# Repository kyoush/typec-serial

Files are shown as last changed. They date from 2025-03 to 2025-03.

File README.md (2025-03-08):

# typec-serial

USB Type-C to serial UART変換基板のKiCadプロジェクト

## 仕様

- ホストPC接続インタフェース: USB Type-C レセプタクル
- UARTデバイス接続インタフェース: 2.54mmピッチ4pinピンヘッダ \
  (実際の通信は、GND, RX, TXだけ使用、残りは3.3V OUTPUT)
- 表示: RX, TXの通信状態をそれぞれLED表示する

## 参考文献

1. じがへるつ, 技術の泉シリーズ　はじめてのType-C電子工作 (株式会社インプレス, 東京, 2024).
2. じがへるつ, 最強FTDIの新定番 USB-シリアルIC大研究, トランジスタ技術 第62巻, 第3号, pp.63-67, (2025).

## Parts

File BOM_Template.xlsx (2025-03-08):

*Reference | *Manufacturer Part number | *QTY | *Original | Description | Purchase Link
C1,C2,C3 | PKMCS0909E4000-R1 | 3 | Y | 0.1u
C4 |  | 1 | Y | 0.47u
D1,D2 |  | 2 | Y
IC1 |  | 1 | Y
R1,R2 |  | 2 | Y | 5.1k
R3,R4 |  | 2 | Y | 27
R5,R6 |  | 2 | Y | 1k
IC1 | NJM12888F33-TE1 | 1 | Y |  | https://www.digikey.jp/ja/products/detail/nisshinbo-micro-devices-inc/NJM12888F33-TE1/10671834
U1 | FT230XS-R | 1 | Y |  | https://www.digikey.jp/ja/products/detail/ftdi-future-technology-devices-international-ltd/FT230XS-R/3029141
J1 | USB4085-GF-A | 1 | Y | NOT ASSEMBLY | https://www.digikey.jp/ja/products/detail/gct/USB4085-GF-A/9859662
Declare：
All ICs will be original even you selected Not original required.
Original: Y means must use the original brand model, N means that you can accept the substitutes with similar spec

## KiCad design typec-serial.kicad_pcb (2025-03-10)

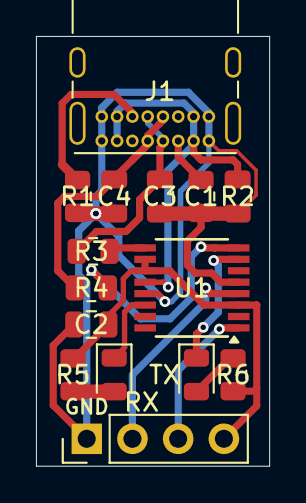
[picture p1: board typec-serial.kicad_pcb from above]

Board: 2 copper layers, 13.0 x 23.9 mm, 15 parts (0 on the bottom side), 15 nets.

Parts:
C1, C2: 0.1u; C_0805_2012Metric
C3, C4: C; C_0805_2012Metric
GND: Conn_01x04_Pin; PinHeader_1x04_P2.54mm_Vertical
J1: USB4085-GF-A_REVB; USB_C_Receptacle_GCT_USB4085
R1, R2: 5.1k; R_0805_2012Metric
R3, R4: 27; R_0805_2012Metric
R5, R6: 470; R_0805_2012Metric
RX: LED_0805_2012Metric
TX: LED_0805_2012Metric
U1: FT230XS; SSOP-16_3.9x4.9mm_P0.635mm

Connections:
GND: C1.1, C2.1, C3.2, C4.2, GND.1, J1.A1 (GND), J1.A12 (GND__1), J1.B1 (GND__2), J1.B12 (GND__3), R1.2, R2.2, U1.5 (GND), U1.13 (GND)
unnamed: R5.2, RX.2 (A)
unnamed: RX.1 (K), U1.14 (CBUS1)
unnamed: R6.1, TX.2 (A)
unnamed: TX.1 (K), U1.7 (CBUS2)
unnamed: J1.A5 (CC1), R2.1
unnamed: J1.B5 (CC2), R1.1
unnamed: C4.1, J1.A7 (DN1), J1.B7 (DN2), R4.1
unnamed: C3.1, J1.A6 (DP1), J1.B6 (DP2), R3.1
unnamed: C1.2, J1.A4 (VBUS), J1.A9 (VBUS__1), J1.B4 (VBUS__2), J1.B9 (VBUS__3), U1.12 (VCC)
unnamed: GND.2, U1.4 (RXD)
unnamed: GND.3, U1.1 (TXD)
unnamed: C2.2, GND.4, R5.1, R6.2, U1.3 (VCCIO), U1.10 (3V3OUT), U1.11 (~RESET)
unnamed: R3.2, U1.9 (USBDM)
unnamed: R4.2, U1.8 (USBDP)

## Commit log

2025-03-08 add BOM
    [BOM_Template.xlsx]
2025-03-08 :rocket: 1st production release
    [typec-serial-B_Cu.gbl, typec-serial-B_Mask.gbs, typec-serial-B_Silkscreen.gbo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]
2025-03-10 :fire: remove regulator
    [typec-serial.kicad_pcb, typec-serial.kicad_sch]
2025-03-10 :rocket: 2nd production
    [pcbname.GBL, pcbname.GBO, pcbname.GBS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]
